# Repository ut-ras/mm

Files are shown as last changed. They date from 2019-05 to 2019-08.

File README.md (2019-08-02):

# Micromouse 2019
UT RAS Micromouse repository for 2019

The repository is structured with hardware eagle files under the [pcb](./pcb) directory and the esp-idf projects under the [software/test-programs](./software/test-programs) directory. To make or flash a program move into a project folder corresponding to that program and run either `make` or `make flash` respectively.
## Setup Software
- Download and Install esp-idf which can be found [here](https://docs.espressif.com/projects/esp-idf/en/latest/get-started/#setting-up-development-environment)
- Download and build software
```bash
git clone https://github.com/ut-ras/mm19
cd software
make
```

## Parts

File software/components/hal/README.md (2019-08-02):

# HAL

HAL is a little special: it's an ESP-IDF component _and also_ a project (as in you can run it!). The project part is sample 'client' code for the HAL; test programs that use it's public interface.

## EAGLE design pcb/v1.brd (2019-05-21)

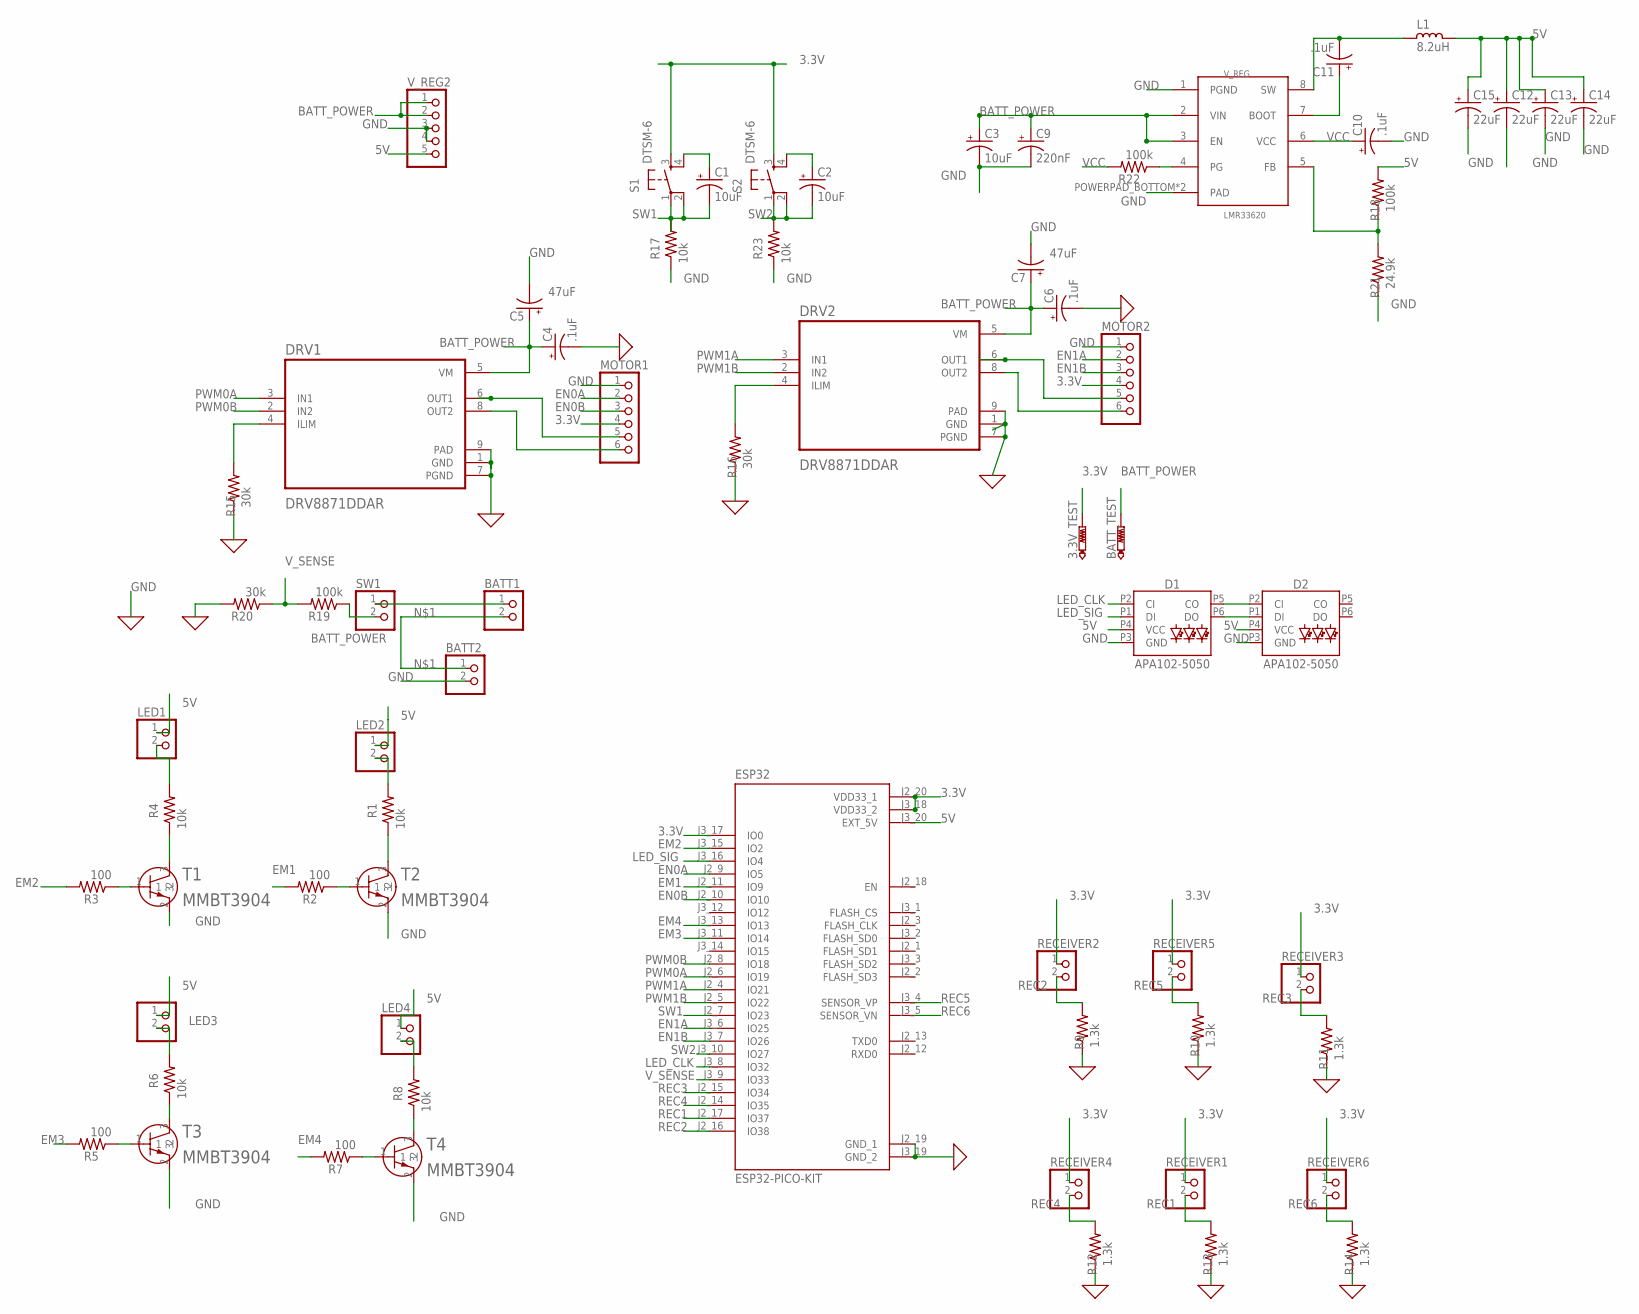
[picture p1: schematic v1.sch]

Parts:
3.3V_TEST: PTR1B1,27; B1,27
BATT1, BATT2: PINHD-1X2; 1X02
BATT_TEST: PTR1B1,27; B1,27
C1, C2, C3: 10uF; A/3216-18R
C4, C6, C10, C11: .1uF; A/3216-18R
C5, C7: 47uF; 150CLZ-0810
C9: 220nF; A/3216-18R
C12, C13, C14, C15: 22uF; A/3216-18R
D1, D2: APA102-5050
DRV1, DRV2: DRV8871DDAR; SOIC127P600X170-8N
ESP32: ESP32-PICO-KIT; XCVR_ESP32-PICO-KIT
L1: 8.2uH; PM1812
LED1, LED2, LED3, LED4: PINHD-1X2; 1X02
MOTOR1, MOTOR2: PINHD-1X6; 1X06
R1, R4, R6, R8, R17, R23: 10k; M1206
R2, R3, R5, R7: 100; M1206
R9, R10, R11, R12, R13, R14: 1.3k; M1206
R15, R16, R20: 30k; M1206
R18, R19, R22: 100k; M1206
R21: 24.9k; M1206
RECEIVER1, RECEIVER2, RECEIVER3, RECEIVER4, RECEIVER5, RECEIVER6: PINHD-1X2; 1X02
S1, S2: DTSM-6
SW1: PINHD-1X2; 1X02
T1, T2, T3, T4: MMBT3904; SOT23
V_REG: LMR33620; SO-8_POWERPAD
V_REG2: PINHD-1X5; 1X05

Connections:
3.3V: 3.3V_TEST.TP, ESP32.J2_20 (VDD33_1), ESP32.J3_17 (IO0), ESP32.J3_18 (VDD33_2), MOTOR1.4, MOTOR2.4, RECEIVER1.1, RECEIVER2.1, RECEIVER3.1, RECEIVER4.1, RECEIVER5.1, RECEIVER6.1, S1.3, S2.3
5V: C12.+, C13.+, C14.+, C15.+, D1.P4 (VCC), D2.P4 (VCC), ESP32.J3_20 (EXT_5V), L1.1, LED1.1, LED2.1, LED3.1, LED4.1, R18.2, V_REG2.5
BATT_POWER: BATT_TEST.TP, C3.+, C4.+, C5.+, C6.+, C7.+, C9.+, DRV1.5 (VM), DRV2.5 (VM), R19.1, SW1.2, V_REG.2 (VIN), V_REG.3 (EN), V_REG2.1, V_REG2.2
EM1: ESP32.J2_11 (IO9), R2.2
EM2: ESP32.J3_15 (IO2), R3.2
EM3: ESP32.J3_11 (IO14), R5.2
EM4: ESP32.J3_13 (IO13), R7.2
EN0A: ESP32.J2_9 (IO5), MOTOR1.2
EN0B: ESP32.J2_10 (IO10), MOTOR1.3
EN1A: ESP32.J3_6 (IO25), MOTOR2.2
EN1B: ESP32.J3_7 (IO26), MOTOR2.3
GND: BATT2.2, C3.-, C4.-, C5.-, C6.-, C7.-, C9.-, C10.-, C12.-, C13.-, C14.-, C15.-, D1.P3 (GND), D2.P3 (GND), DRV1.1 (GND), DRV1.7 (PGND), DRV1.9 (PAD), DRV2.1 (GND), DRV2.7 (PGND), DRV2.9 (PAD), ESP32.J2_19 (GND_1), ESP32.J3_19 (GND_2), MOTOR1.1, MOTOR2.1, R9.1, R10.1, R11.1, R12.1, R13.1, R14.1, R15.1, R16.1, R17.1, R20.2, R21.1, R23.1, T1.2, T2.2, T3.2, T4.2, V_REG.1 (PGND), V_REG.POWERPAD_BOTTOM (PAD), V_REG.POWERPAD_TOP (PAD), V_REG2.3, V_REG2.4
LED3: LED3.2, R6.2
LED_CLK: D1.P2 (CI), ESP32.J3_8 (IO32)
LED_SIG: D1.P1 (DI), ESP32.J3_16 (IO4)
unnamed: BATT1.2, BATT2.1
unnamed: BATT1.1, SW1.1
unnamed: C1.+, S1.4
unnamed: R2.1, T2.1
unnamed: LED2.2, R1.2
unnamed: R1.1, T2.3
unnamed: LED1.2, R4.2
unnamed: R4.1, T1.3
unnamed: R5.1, T3.1
unnamed: R6.1, T3.3
unnamed: R7.1, T4.1
unnamed: LED4.2, R8.2
unnamed: R8.1, T4.3
unnamed: DRV1.8 (OUT2), MOTOR1.6
unnamed: DRV1.6 (OUT1), MOTOR1.5
unnamed: DRV2.8 (OUT2), MOTOR2.6
unnamed: DRV2.6 (OUT1), MOTOR2.5
unnamed: DRV2.4 (ILIM), R16.2
unnamed: C2.+, S2.4
unnamed: R18.1, R21.2, V_REG.5 (FB)
unnamed: DRV1.4 (ILIM), R15.2
unnamed: C11.+, V_REG.7 (BOOT)
unnamed: C11.-, L1.2, V_REG.8 (SW)
unnamed: D1.P5 (CO), D2.P2 (CI)
unnamed: D1.P6 (DO), D2.P1 (DI)
PG: R22.1, V_REG.4 (PG)
PWM0A: DRV1.3 (IN1), ESP32.J2_6 (IO19)
PWM0B: DRV1.2 (IN2), ESP32.J2_8 (IO18)
PWM1A: DRV2.3 (IN1), ESP32.J2_4 (IO21)
PWM1B: DRV2.2 (IN2), ESP32.J2_5 (IO22)
REC1: ESP32.J2_17 (IO37), R13.2, RECEIVER1.2
REC2: ESP32.J2_16 (IO38), R9.2, RECEIVER2.2
REC3: ESP32.J2_15 (IO34), R11.2, RECEIVER3.2
REC4: ESP32.J2_14 (IO35), R12.2, RECEIVER4.2
REC5: ESP32.J3_4 (SENSOR_VP), R10.2, RECEIVER5.2
REC6: ESP32.J3_5 (SENSOR_VN), R14.2, RECEIVER6.2
SW1: C1.-, ESP32.J2_7 (IO23), R17.2, S1.1, S1.2
SW2: C2.-, ESP32.J3_10 (IO27), R23.2, S2.1, S2.2
T1: R3.1, T1.1
VCC: C10.+, R22.2, V_REG.6 (VCC)
V_SENSE: ESP32.J3_9 (IO33), R19.2, R20.1

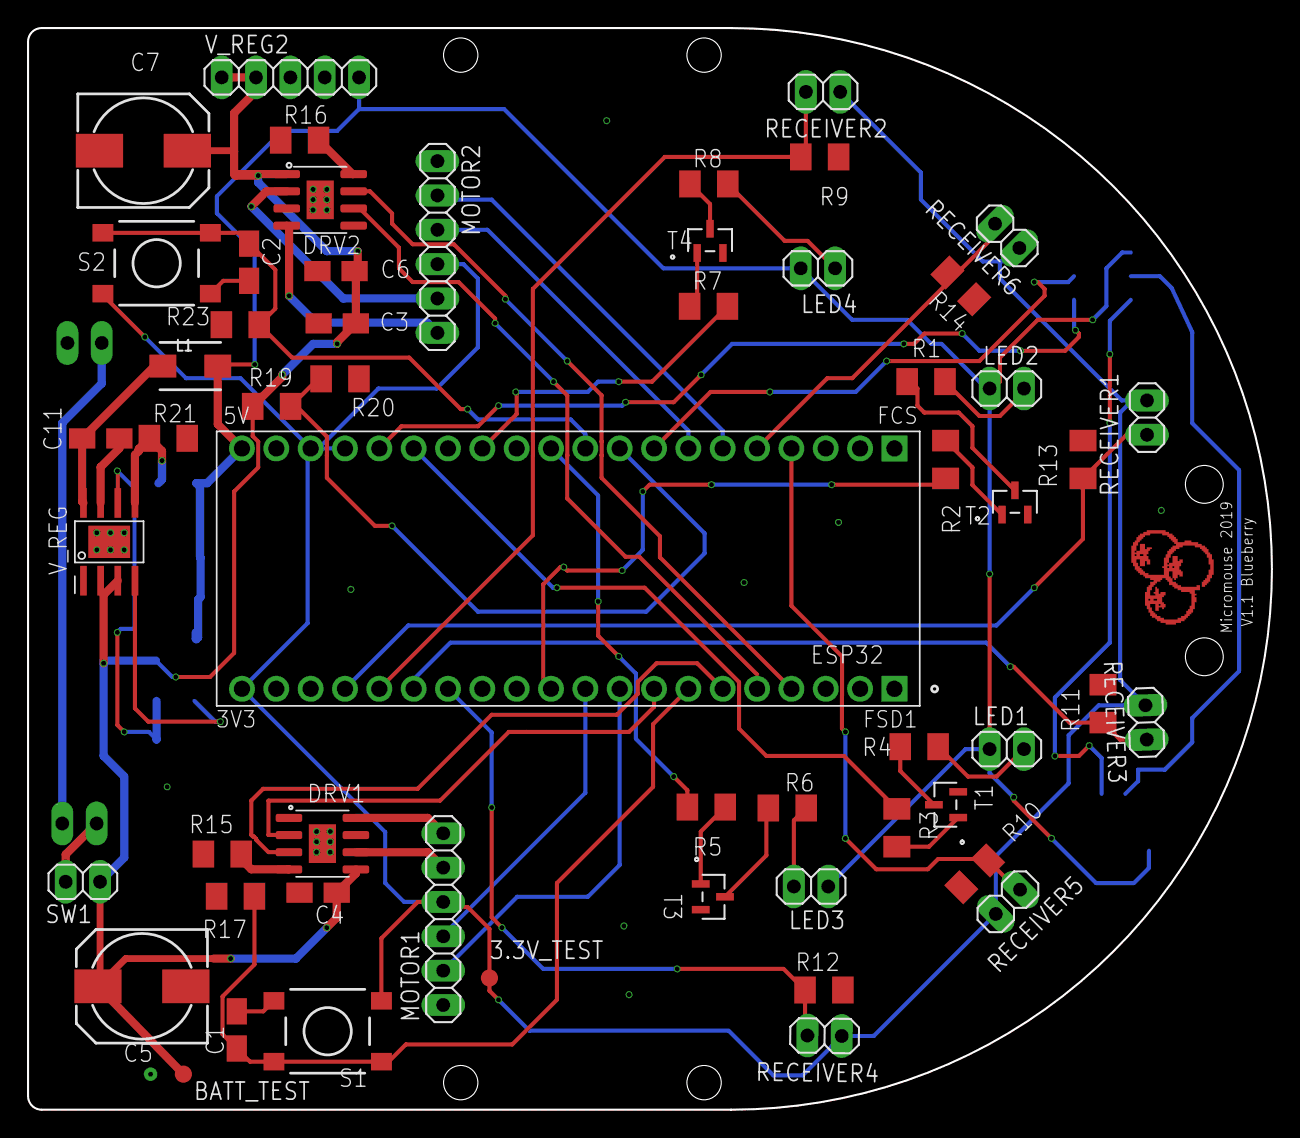
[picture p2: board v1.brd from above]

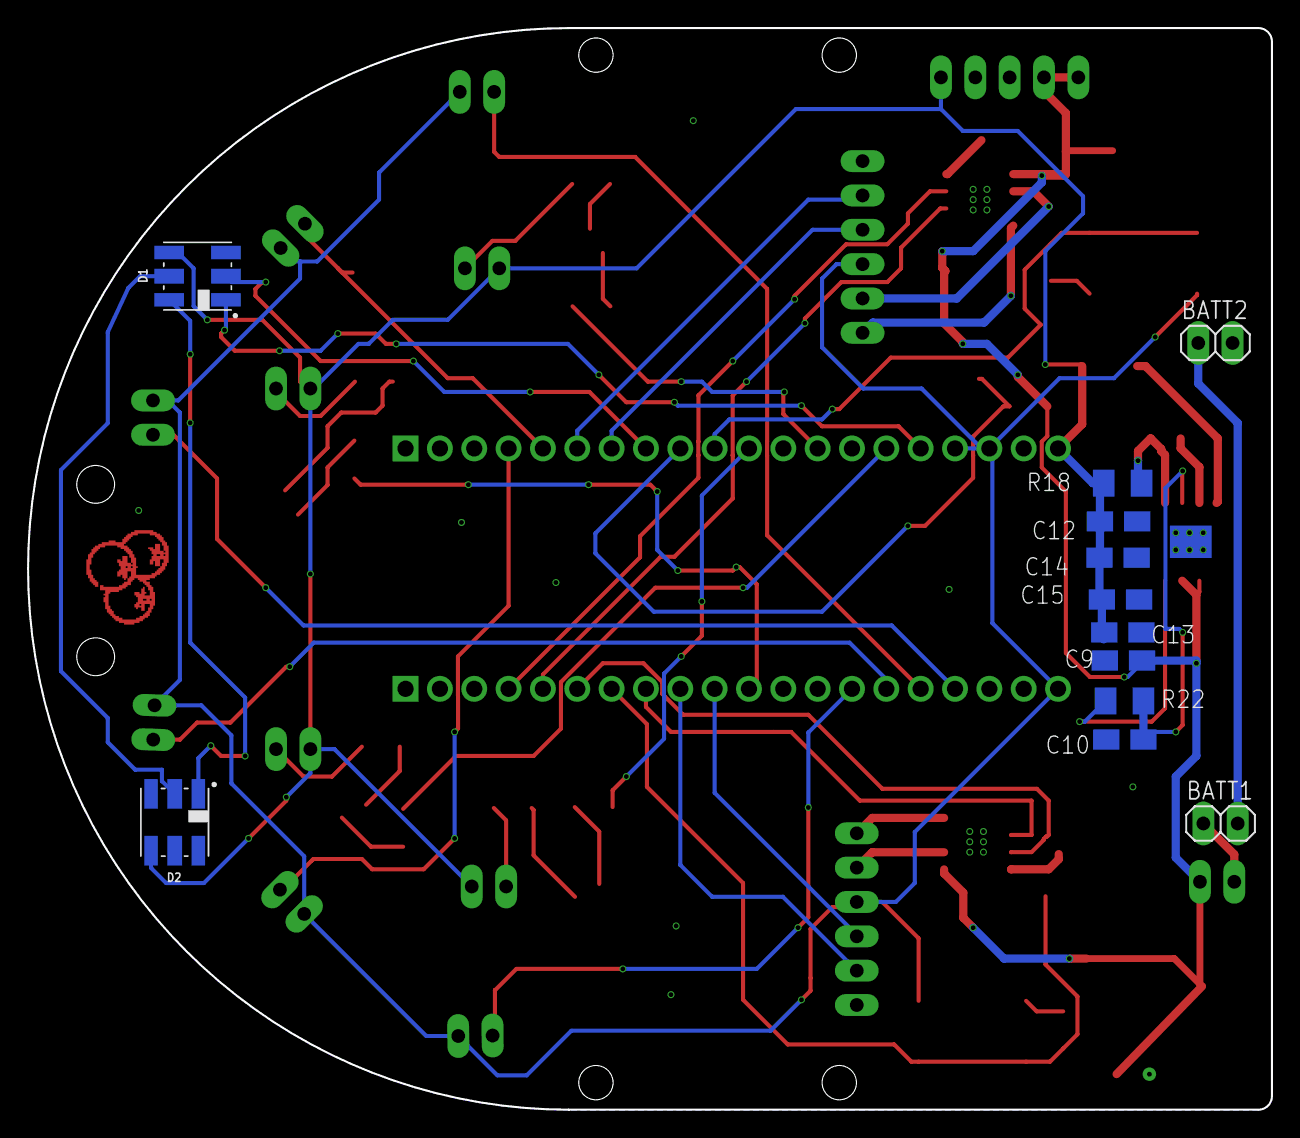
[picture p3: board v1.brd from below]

Board: 2 copper layers, 92.0 x 80.0 mm, 68 parts (12 on the bottom side), 56 nets.

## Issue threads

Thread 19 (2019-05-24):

Move Recievers forwards to avoid intersecting with wheels

TheVamsiG, 2019-05-24:

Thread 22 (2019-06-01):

Remove short between 3.3V and IO0

TheVamsiG, 2019-06-01:

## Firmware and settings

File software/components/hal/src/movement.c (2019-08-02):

#include "movement.h"
#include <assert.h>
#include <math.h>
#include <stdlib.h>
#include "apa102.h"
#include "battery.h"
#include "distance.h"
#include "enc.h"
#include "freertos/FreeRTOS.h"
#include "freertos/task.h"
#include "motorController.h"
#include "pid.h"

#define LEFT_FRONT_PIN 37
#define LEFT_SIDE_PIN 38
#define LEFT_EMITTER 15

#define RIGHT_FRONT_PIN 34
#define RIGHT_SIDE_PIN 35
#define RIGHT_EMITTER 2

#define TURN_TICKS 90
#define ENC_DIFF 0

#define MOVE_DELAY 200
#define TIMEOUT_DIFF 100

#define LED_DATA_PIN 4
#define LED_CLK_PIN 32

int LEFT_SIDE_ZERO = 510;
int LEFT_SIDE_THRESH = 330;
int RIGHT_SIDE_ZERO = 590;
int RIGHT_SIDE_THRESH = 300;

int LEFT_FRONT_ZERO = 300;
int LEFT_FRONT_THRESH = 510;
int RIGHT_FRONT_ZERO = 300;
int RIGHT_FRONT_THRESH = 310;

distance left;
distance right;

PID* movePID;
PID* turn90PID;
PID* turn180PID;
PID* moveEncPID;
PID* turnDegreePID;

LedStrip* leds;

int init() {
  if (init_distance_sensor(&left, LEFT_FRONT_PIN, LEFT_SIDE_PIN,
                           LEFT_EMITTER)) {
    printf("Init sensor left failed");
    return 1;
  }
  if (init_distance_sensor(&right, RIGHT_FRONT_PIN, RIGHT_SIDE_PIN,
                           RIGHT_EMITTER)) {
    printf("Init sensor right failed");
    return 2;
  }

  // Initialize Encoders
  enc_init();

  // mcpwm_example_gpio_initialize();
  mcpwm_initialize();

  movePID = initPID(0.00035, 0.001, 0.000, "log");

  turn90PID = initPID(0.8, 0.1, 0.0, "log");

  turn180PID = initPID(0.5, 0.1, 0.0, "log");

  moveEncPID = initPID(0.045, 0, 0, "log");

  turnDegreePID = initPID(0.1, 0.05, 0.00, "log");

  initBattery();

  printf("Battery: %d\n", getBatteryVal());

  leds = new_led_strip(HSPI_HOST, LED_DATA_PIN, LED_CLK_PIN, 2);
  color_single(leds, RGB_COLOR(0xFF, 0xFF, 0xFF));

  return 0;
}

void zero(void) {
  int dists[2];

  read_distance(&left, dists);
  LEFT_FRONT_ZERO = dists[0];
  LEFT_SIDE_ZERO = dists[1];

  read_distance(&right, dists);
  RIGHT_FRONT_ZERO = dists[0];
  RIGHT_SIDE_ZERO = dists[1];
}

struct movement_info getWalls(int* lsensor, int* rsensor) {
  int leftDists[2];
  int rightDists[2];

  read_distance(&left, leftDists);

  read_distance(&right, rightDists);

  struct movement_info info;
  info.left = leftDists[1] > LEFT_SIDE_THRESH;
  info.right = rightDists[1] > RIGHT_SIDE_THRESH;

  info.front = (leftDists[0] > LEFT_FRONT_THRESH && leftDists[1] < 900 &&
                rightDists[0] > 0) ||
               (rightDists[0] > RIGHT_FRONT_THRESH && rightDists[1] < 1500 &&
                leftDists[0] > 0);

  if (lsensor) *lsensor = leftDists[1];
  if (rsensor) *rsensor = rightDists[1];

  return info;
}

static int calcIRError(int sideLeft, int sideRight) {
  int error = 0;
  if (sideLeft > LEFT_SIDE_THRESH)
    error += LEFT_SIDE_ZERO - sideLeft;
  if (sideRight > LEFT_SIDE_THRESH)
    error += sideRight - RIGHT_SIDE_ZERO;
  return error;
}

struct movement_info moveIR(float speed) {
  double lastTime = esp_timer_get_time() / 1000000.0;
  double currentTime;

  int sideLeft;
  int sideRight;

  set(movePID, 0);

  int startEnc = getAbsAvgTicks();
  int leftStart = abs(getTicks(left_enc));
  int rightStart = abs(getTicks(right_enc));

  struct movement_info info = getWalls(&sideLeft, &sideRight);
  calcIRError(sideLeft, sideRight);

  while (!info.front && info.left && info.right) {
    currentTime = esp_timer_get_time() / 1000000.0;
    double diffTime = currentTime - lastTime;
    lastTime = currentTime;

    double curr = update(movePID, calcIRError(sideLeft, sideRight), diffTime);
    // printf("sens %d %d\n", frontLeft, frontRight);
    // printf("curr %f %d \n", curr, readIRError(&frontLeft, &sideLeft,
    // &frontRight, &sideRight));
    setMotors(speed + curr, speed - curr);
    info = getWalls(&sideLeft, &sideRight);
  }
  stopMotors();

  vTaskDelay(MOVE_DELAY / portTICK_RATE_MS);

  info = getWalls(NULL, NULL);

  info.ticksTraveled = (getAbsAvgTicks() - startEnc);
  int encDiff = (abs(getTicks(left_enc)) - leftStart) -
                (abs(getTicks(right_enc)) - rightStart);

  // turnDegrees(encDiff > 0 ? -8.5 : 8.5, abs(encDiff));

  return info;
}
struct movement_info moveIRU(float speed) {
  double lastTime = esp_timer_get_time() / 1000000.0;
  double currentTime;

  int sideLeft;
  int sideRight;

  set(movePID, 0);

  int startEnc = getAbsAvgTicks();

  color_single(leds, RGB_COLOR(0xFF, 0, 0));

  struct movement_info info = getWalls(&sideLeft, &sideRight);
  calcIRError(sideLeft, sideRight);

  while (getAbsAvgTicks() - startEnc < 80 && !info.front) {
    currentTime = esp_timer_get_time() / 1000000.0;
    double diffTime = currentTime - lastTime;
    lastTime = currentTime;

    double curr = update(movePID, calcIRError(sideLeft, sideRight), diffTime);
    // printf("sens %d %d\n", frontLeft, frontRight);
    // printf("curr %f %d \n", curr, readIRError(&frontLeft, &sideLeft,
    // &frontRight, &sideRight));
    setMotors(speed + curr, speed - curr);
    info = getWalls(&sideLeft, &sideRight);
  }
  stopMotors();
  color_single(leds, RGB_COLOR(0x00, 0xFF, 0));

  moveEnc(speed, 128);
  info = getWalls(NULL, NULL);

  info.ticksTraveled = (getAbsAvgTicks() - startEnc);

  return info;
}

static int turnProg(int start) { return abs(getAvgTicks() - start); }

static double pid_get_time() { return esp_timer_get_time() / 1000000.0; }

inline static double signum(double num) { return num < 0.0 ? -1.0 : 1.0; }

struct movement_info turnTicks(PID* pid, float dir, int num_ticks);

struct movement_info turn90(float speed) {
  return turnTicks(turn90PID, speed, TURN_TICKS);
}

struct movement_info turn180(float speed) {
  return turnTicks(turn180PID, speed, 2 * TURN_TICKS);
}
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

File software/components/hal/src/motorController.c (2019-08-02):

#include <stdbool.h>
#include "driver/mcpwm.h"

#define GPIO_PWM0A_OUT 19  // Set GPIO 19 as PWM0A
#define GPIO_PWM0B_OUT 18  // Set GPIO 18 as PWM0B
#define GPIO_PWM1A_OUT 22  // Set GPIO 22 as PWM1A
#define GPIO_PWM1B_OUT 21  // Set GPIO 21 as PWM1B

#define PWM_FREQ 100
#define BRAKING false

/**
 * @brief Configure whole MCPWM module
 */
static void mcpwm_frequency_initialize() {
  mcpwm_config_t pwm_config;
  pwm_config.frequency = PWM_FREQ;  // frequency = 100Hz
  pwm_config.cmpr_a = 0.0;          // duty cycle of PWMxA = 0.0%
  pwm_config.cmpr_b = 0.0;          // duty cycle of PWMxb = 0.0%
  pwm_config.counter_mode = MCPWM_UP_COUNTER;
  pwm_config.duty_mode = MCPWM_DUTY_MODE_0;
  mcpwm_init(
      MCPWM_UNIT_0, MCPWM_TIMER_0,
      &pwm_config);  // Configure PWM0A(19) & PWM0B(18) with above settings
  // connect 19 and 18 to a single motors
  pwm_config.frequency = PWM_FREQ;  // frequency = 100Hz
  pwm_config.cmpr_a = 0.0;          // duty cycle of PWMxA = 0.0%
  pwm_config.cmpr_b = 0.0;          // duty cycle of PWMxb = 0.0%
  pwm_config.counter_mode = MCPWM_UP_COUNTER;
  pwm_config.duty_mode = MCPWM_DUTY_MODE_0;
  mcpwm_init(
      MCPWM_UNIT_0, MCPWM_TIMER_1,
      &pwm_config);  // Configure PWM1A(21) & PWM1B(22) with above settings
}

/*
 * Call this initialize before starting to set speed of the both motors
 */
void mcpwm_initialize() {
  printf("initializing mcpwm gpio...\n");
  mcpwm_gpio_init(MCPWM_UNIT_0, MCPWM0A, GPIO_PWM0A_OUT);
  mcpwm_gpio_init(MCPWM_UNIT_0, MCPWM0B, GPIO_PWM0B_OUT);
  mcpwm_gpio_init(MCPWM_UNIT_0, MCPWM1A, GPIO_PWM1A_OUT);
  mcpwm_gpio_init(MCPWM_UNIT_0, MCPWM1B, GPIO_PWM1B_OUT);
  mcpwm_frequency_initialize();
}

// speed is positive to go forward, negative to go backward. -100 to 100.
void setLeftSpeed(double speed) {
  if (speed == 0 && BRAKING) {
    mcpwm_set_signal_high(MCPWM_UNIT_0, MCPWM_TIMER_1, MCPWM_OPR_A);
    mcpwm_set_signal_high(MCPWM_UNIT_0, MCPWM_TIMER_1, MCPWM_OPR_B);
    return;
  }

  if (speed > 0) {
    mcpwm_set_signal_low(MCPWM_UNIT_0, MCPWM_TIMER_1, MCPWM_OPR_B);
    mcpwm_set_duty(MCPWM_UNIT_0, MCPWM_TIMER_1, MCPWM_OPR_A, speed);
    mcpwm_set_duty_type(MCPWM_UNIT_0, MCPWM_TIMER_1, MCPWM_OPR_A,
                        MCPWM_DUTY_MODE_0);
  } else if (speed <= 0) {
    mcpwm_set_signal_low(MCPWM_UNIT_0, MCPWM_TIMER_1, MCPWM_OPR_A);
    mcpwm_set_duty(MCPWM_UNIT_0, MCPWM_TIMER_1, MCPWM_OPR_B, -speed);
    mcpwm_set_duty_type(MCPWM_UNIT_0, MCPWM_TIMER_1, MCPWM_OPR_B,
                        MCPWM_DUTY_MODE_0);
  }
}

// speed is positive to go forward, negative to go backward. -100 to 100.
void setRightSpeed(double speed) {
  if (speed == 0 && BRAKING) {
    mcpwm_set_signal_high(MCPWM_UNIT_0, MCPWM_TIMER_0, MCPWM_OPR_A);
    mcpwm_set_signal_high(MCPWM_UNIT_0, MCPWM_TIMER_0, MCPWM_OPR_B);
    return;
  }

  if (speed > 0) {
    mcpwm_set_signal_low(MCPWM_UNIT_0, MCPWM_TIMER_0, MCPWM_OPR_B);
    mcpwm_set_duty(MCPWM_UNIT_0, MCPWM_TIMER_0, MCPWM_OPR_A, speed);
    mcpwm_set_duty_type(MCPWM_UNIT_0, MCPWM_TIMER_0, MCPWM_OPR_A,
                        MCPWM_DUTY_MODE_0);
  } else if (speed <= 0) {
    mcpwm_set_signal_low(MCPWM_UNIT_0, MCPWM_TIMER_0, MCPWM_OPR_A);
    mcpwm_set_duty(MCPWM_UNIT_0, MCPWM_TIMER_0, MCPWM_OPR_B, -speed);
    mcpwm_set_duty_type(MCPWM_UNIT_0, MCPWM_TIMER_0, MCPWM_OPR_B,
                        MCPWM_DUTY_MODE_0);
  }
}

void setMotors(float left, float right) {
  setLeftSpeed(left);
  setRightSpeed(-right);
}

void stopMotors(void) { setMotors(0.0, 0.0); }

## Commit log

2018-10-24 first commit. V1.0 implementation of classes for the simulation and C/C++ conversion. Documented. Needs driver with algorithm rebuilt. Needs basic testing driver.
2018-12-01 removed bool for Neighbor, replaced with a -1, 0, 1 and a #define UNKNOWN, TRUE, FALSE in the main mouse method that uses neighbor's pathbool; cleaned up control flow for findDir in mouse.c
2018-12-08 wrote up node.c, alterations to neighbor, built a main tester and a makefile, currently unit testing looks good, needs to finish implmenting and rebuilding addRelation method of node.c, also testing 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
2018-12-08 rebuilt main to test cohesive classes, edited makefile, works, needs sensor functions to test actual mazesolving, also addrelations needs to be completed
2019-03-30 working encoders
2019-03-30 initialize second encoder
2019-04-08 Changed 5V receiver inputs to 3.3V
    [v1.brd, v1.sch]
2019-04-08 Added Smd led
    [v1.brd, v1.sch]
2019-04-08 Fixed led positioning and adc pins
    [v1.brd, v1.sch]
2019-04-08 Changed 5V line
    [v1.brd]
2019-04-08 Changed pin placement
    [v1.brd, v1.sch]
2019-04-08 Flipped the back sensor resistors
    [v1.brd]
2019-04-08 Evened out the holes to make pcb look nicer
    [v1.brd]
2019-04-10 Changed the voltage regulator and updated the pcb
    [v1.brd, v1.sch]
2019-04-10 Changed the resistive voltage divider values
    [v1.brd, v1.sch]
2019-04-10 Added ground plane
    [v1.brd]
2019-04-13 Added Strawberry
    [v1.brd]
2019-04-13 initial pid code, pid_ctl unfinished
2019-04-13 Changed strawberry and caps. Added gerber files
    [v1.brd, v1.sch]
2019-04-13 Last minute touches to PCB Moved headers for motor and led to not interfere with nuts. Made ground plane solid instead of hatched. Fixed silkscreen overlap. Connected ground planes for top and bottom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
    [v1.brd, v1.sch]
2019-04-19 implementing mouse, maze, cut down maze functions for a cheaper query function
2019-05-10 add documentation for pid and enc code
2019-05-14 Changed PCB
    Fixes #11
    Fixes #10
    Fixes #9
    Fixes #8
    [v1.brd, v1.sch]
2019-05-14 Cosmetic Changes
    [v1.brd, v1.sch]
2019-05-14 Fixed direction of motor
    [motorController.c]
2019-05-14 blueberry: not 🍅
    [v1.brd, v1.sch]
2019-05-14 blueberry: 📐
    [v1.brd]
2019-05-21 Made connnecting grounds
    [v1.brd, v1.sch]
2019-05-21 Changed ground plane
    [v1.brd]
2019-05-21 Removed overlap
    [v1.brd]
2019-05-21 Changed locations of the holes
    [v1.brd]
2019-05-24 Added sensortest and started testing correction for moveIR
    [movement.c]
2019-05-28 Tuned PID values and fixed bug related to IR Zeros
    [movement.c]
2019-05-30 misc: clang-format + .gitignore things
    and a precommit hook!
    If you reached this commit while trying to trace through the commit history, I'm sorry.
2019-05-30 hal: add a pin-map component stub
2019-05-31 "Basic move encoder code"
2019-06-01 Cleaned PID to work with wall follow
    TODO tune the turning because MAX_SUM was change
2019-06-01 Added nav, fixed moveEnc and changed PID values
    [enc.c, movement.c]
2019-06-02 pid: changes to turn90
2019-06-02 pid: untested changes :-)
2019-06-02 flip wall logic from movement.
    [mouse_interface.cpp]

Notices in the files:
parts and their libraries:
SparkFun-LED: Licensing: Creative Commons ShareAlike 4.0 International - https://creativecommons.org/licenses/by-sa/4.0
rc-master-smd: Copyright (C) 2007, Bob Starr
